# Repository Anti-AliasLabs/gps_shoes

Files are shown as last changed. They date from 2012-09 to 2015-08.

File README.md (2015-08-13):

gps_shoes
=========

Project with Dominc Wilcox and Stamp Shoes to create GPS shoes.

ChooseHome is a Processing sketch to select the location for the shoes to guide to.
Requires Processing 1.5.1 and Processing libraries:

* [Unfolding](http://unfoldingmaps.org/)
* [GLGraphics](http://glgraphics.sourceforge.net/)
* [guicomponents](https://code.google.com/p/gui4processing/downloads/list)
* [processing-http](https://github.com/francisli/processing-http/wiki)

Bill of Materials
-----------------

V1

* Arduino Pro Mini
* [LiPo Charger](https://www.sparkfun.com/products/11231)
* [Kingbright LEDs](https://uk.rs-online.com/web/p/visible-leds/4663970/)
* Reed switch
* [GPS](https://www.sparkfun.com/products/8975)
* [Cable assembly](https://uk.rs-online.com/web/p/industrial-automation-cable-assemblies/6813155/)
* [PCB Header](https://uk.rs-online.com/web/p/pcb-headers/6813111/)
* [Connector housing](https://uk.rs-online.com/web/p/pcb-connector-housings/6813082/)

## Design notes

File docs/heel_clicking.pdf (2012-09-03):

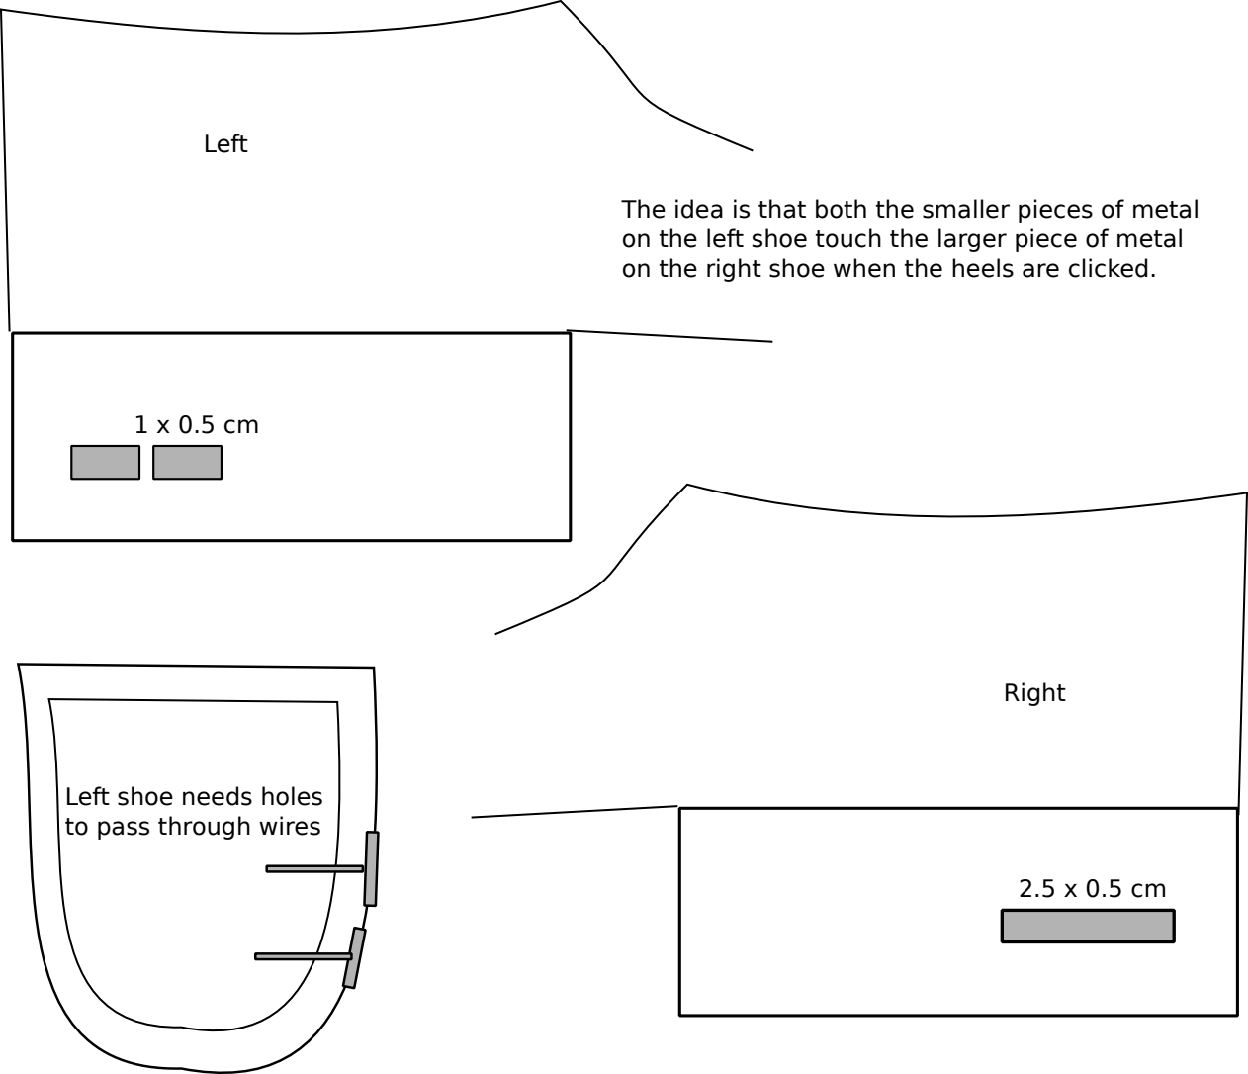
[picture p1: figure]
Left; Right; Left shoe needs holes to pass through wires

The idea is that both the smaller pieces of metal on the left shoe touch the larger piece of metal on the right shoe when the heels are clicked.

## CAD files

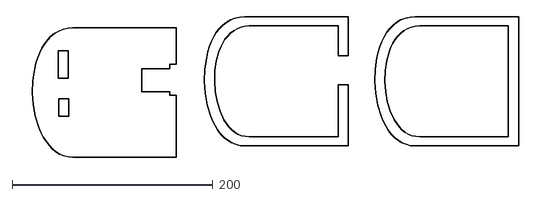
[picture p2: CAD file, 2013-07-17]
docs/heel_boxes.dxf
500.0 x 140.7

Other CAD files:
docs/heel_boxes_.dxf

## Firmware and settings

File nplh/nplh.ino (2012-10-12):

/* 
 No Place Like Home
 Becky Stewart
 Codasign
 becky@codasign.com
 July 2012
 
 Serial port reads in GPS data and writes out
 instructions to remote XBee controlling LEDS.
 
 
 
 */

#include <TinyGPS.h>
#include <VirtualWire.h>
#include <SoftwareSerial.h>

SoftwareSerial softSerial(3, 4); // RX, TX

const int gpsIn = 1;
const int heelPin = 2;

int centreLED = 5;
int ledPins[] = {
  6, 13, 14, 15, 16, 17, 8, 7};

int ledsLen = 8;
/*
 N  6
 NE 13
 E  14
 SE 15
 S  16
 SW 17
 W  8
 NW 7
 */

int fadeValue = 0;
int fadeDirection = 2;

unsigned long lastGPSfeed;

const unsigned long timeLimit = 5000;
const int triggerNum = 3;

unsigned long initDetect;
int currCount = 0;

int goHome = 0;


int headingValue;
float startLat = 0.0;
float startLon = 0.0;

TinyGPS gps;

float homeLat = 37.6922, homeLon = 97.3372;

//---------------------------------------------------------------------------------
// setup - called once at startup
//---------------------------------------------------------------------------------
void setup()
{
  Serial.begin(57600);
  softSerial.begin(9600);

  // set up interrupt for heel clicks
  pinMode(heelPin, INPUT); 
  digitalWrite(heelPin, HIGH);
  attachInterrupt(0, heelClicked, CHANGE);

  // set up LED display
  for (int i=0; i<ledsLen; i++){
    pinMode(ledPins[i], OUTPUT); 
  }

  // Initialise the IO and ISR
  vw_set_ptt_inverted(true); // Required for DR3100
  vw_setup(2000);	 // Bits per sec

  // initialise GPS reading timer
  lastGPSfeed = millis();
}

//---------------------------------------------------------------------------------
// loop - called continuously while powered
//---------------------------------------------------------------------------------
void loop()
{
  bool newdata = false;
  unsigned long loopStart = millis();

  // if it's been longer than the time limit
  // reset the counter
  if ( currCount > 0 && (loopStart-initDetect) > timeLimit )
  {
    currCount = 0; 
    softSerial.println("resetting counter");
  }

  // heels have been clicked
  if ( currCount >= triggerNum && (timeLimit-initDetect) )
  {
    // print the results to the serial monitor:
    softSerial.print("starting directions " );  
    softSerial.println(currCount);
    currCount = 0;
    goHome = 1;
  }

  // we are showing directions
  if ( goHome ){
    // Every second we print an update
    while ( millis() - loopStart < 1000)
    {
      if (feedgps())
        newdata = true;
    }
    // spin lights if we don't have a signal
    // show directions if we do
    updateGPS(gps);
  }
  else {
    standby();
  }
}

//---------------------------------------------------------------------------------
// gpsdump - reads in GPS data
//---------------------------------------------------------------------------------
static void updateGPS(TinyGPS &gps)
{
  float flat, flon;
  unsigned long age, date, time, chars = 0;
  unsigned short sentences = 0, failed = 0;
  unsigned long invalid = 0;


  gps.f_get_position(&flat, &flon, &age);

  // if GPS isn't receiving a signal, just flash lights
  if(TinyGPS::GPS_INVALID_F_ANGLE == flat || TinyGPS::GPS_INVALID_F_ANGLE == flon) {
    Serial.println("invalid position"); 
    spinLights();
  }
  // if receiving a signal, go ahead and compute location and distance
  else{
    // get current course
    softSerial.print("Current Latitude: ");
    softSerial.print(flat);
    softSerial.print(" Current Longitude: ");
    softSerial.print(flon);

    // keep track of where we are once we've started 
    // navigating home (to keep track of distance travelled
    // once we start going home)
    if ( goHome && startLat == 0.0 && startLon == 0.0) {
      startLat = flat;
      startLon = flon;
    }

    // update directions
    int total_dist = TinyGPS::distance_between(startLat, startLon, homeLat, homeLon) / 1000;
    int dist_travelled = TinyGPS::distance_between(startLat, startLon, flat, flon) / 1000;
    float current_course = gps.f_course(); 
    float course_to_home = TinyGPS::course_to(flat, flon, homeLat, homeLon);

    // send distance to right shoe for lights
    int d = dist_travelled/total_dist * 6.0;
    sendDistanceToRight(d);
    Serial.print(" Current Course: ");
    Serial.print(TinyGPS::cardinal(gps.f_course()));
    Serial.print(" ");
    Serial.print(current_course);
    Serial.print(" ");

    
    Serial.print(" To go ");
    Serial.print(dist_travelled);
    Serial.print(" ");
    Serial.print(d);
    Serial.print(" ");
    Serial.println(course_to_home);
    const char *str = TinyGPS::cardinal(course_to_home);
    updateLightsHeading(current_course, course_to_home);

  }
}


//---------------------------------------------------------------------------------
// feedgps - returns true if GPS data available
//---------------------------------------------------------------------------------
static bool feedgps()
{
  while (Serial.available())
  {
    if (gps.encode(Serial.read()))
      return true;
  }
  return false;
}

//---------------------------------------------------------------------------------
// heelClicked - increments counter for heel clicks
//---------------------------------------------------------------------------------
void heelClicked() {
  currCount++;
  Serial.println("click");
  // if this is the first knock
  // note the time
  if ( currCount == 1 )
  {
    initDetect = millis(); 
  }
}

//---------------------------------------------------------------------------------
// standby - standby power light
//---------------------------------------------------------------------------------
void standby(){
  // fade centre from min to max in increments of 5 points:
  analogWrite(centreLED, fadeValue);  

  fadeValue += fadeDirection;
  if(fadeValue > 253 || fadeValue < 2)
    fadeDirection = -1*fadeDirection;  


  delay(30);
}

//---------------------------------------------------------------------------------
// spinLights - spinning light pattern
//---------------------------------------------------------------------------------
void spinLights()
{
  digitalWrite(centreLED, LOW);
  for (int i=0; i<ledsLen; i++){
    digitalWrite(ledPins[i], HIGH); 
    delay(200);
    digitalWrite(ledPins[i], LOW); 
  }
}

//---------------------------------------------------------------------------------
// updateLightsHeading - update light indicating north
//---------------------------------------------------------------------------------
void updateLightsHeading(float c, float h)
{
  // turn off all LEDs
  for (int i=0; i<ledsLen; i++){
    digitalWrite(ledPins[i], LOW); 
  }

  //given a heading and a direction, calculate which of 8
  // LEDs should light up (valued 0-7)
  float relativeAngle;
  int ledOn;

  // calculate relative angle 
  relativeAngle = c-h;

  // ensure relative angle is in the range 0-360
  relativeAngle = modulo360((int)relativeAngle);

  // calculate LED based upon borders of (x*45)+22.5 degrees for x = (0...7) 
  ledOn = floor(modulo360(relativeAngle+22.5)/45);

  digitalWrite(centreLED, LOW);
  delay(100);
  digitalWrite(centreLED, HIGH);
  digitalWrite(ledPins[ledOn], HIGH);
  softSerial.println(ledOn);
}

//---------------------------------------------------------------------------------
// modulo360: simple modulo 360. Negative numbers are set within
// the 0-360 range which is not done by built in Processing modulo
//---------------------------------------------------------------------------------
float modulo360(int val)
{
  // ifval is < 0, set it within 0-360
  while (val < 0)
  {
    val = val+360;
  }

  // if val is > 360, set within 0-360
  val = val % 360;

  return val;
}

//---------------------------------------------------------------------------------
// sendDistanceToRight - sends an int between 1 and 6 to right shoe
//---------------------------------------------------------------------------------
void sendDistanceToRight(int dist)
{
  uint8_t msg[] = {
    dist    };

  vw_send(msg, 1);
  vw_wait_tx(); // Wait until the whole message is gone
}

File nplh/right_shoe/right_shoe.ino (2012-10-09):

// receiver
//
// Receiver for right shoe of GPS shoes
// rf receiver in pin 11

#include <VirtualWire.h>

// first LED with PWM fading needs to be in 3 (or same port)
int leds[] = {
  3, 17, 16, 15, 14};
int numLEDs = 5;
int currBlink = 0;

int j =0;
int fadeValue = 0;
int fadeDirection = 5;

void setup()
{
    Serial.begin(9600);	// Debugging only
    Serial.println("setup");
    
    for( int i=0; i<numLEDs; i++)
    {
      pinMode(leds[i], OUTPUT);
    }

    // Initialise the IO and ISR
    vw_set_ptt_inverted(true); // Required for DR3100
    vw_setup(2000);	 // Bits per sec

    vw_rx_start();       // Start the receiver PLL running
}

void loop()
{
    uint8_t buf[VW_MAX_MESSAGE_LEN];
    uint8_t buflen = VW_MAX_MESSAGE_LEN;

    if (vw_get_message(buf, &buflen)) // Non-blocking
    {
	int i;

        digitalWrite(13, true); // Flash a light to show received good message
	// Message with a good checksum received, dump it.
	Serial.print("Got: ");
	
	for (i = 0; i < buflen; i++)
	{
            currBlink = buf[i];
            Serial.print("received: ");
	    Serial.println(currBlink);
	}

        digitalWrite(13, false);
    }
    
    distance_lights(currBlink);
    
    //Serial.println("test");
    //delay(1000);
}


void distance_lights(int pos)
{ 
  //Serial.print("blinking position: ");
  //Serial.println(pos);
  //Serial.print(" ");
  // simulate distance to destination
  if(pos > 0) {
    if(pos < 6){
    for(int i=0; i<=numLEDs-1; i++)
    {
      digitalWrite(leds[i], LOW);
    }

    for(int i=0; i<pos-1; i++){
      digitalWrite(leds[i], HIGH);
    }
    digitalWrite(leds[pos-1], HIGH);
    delay(300);
    digitalWrite(leds[pos-1], LOW);
    delay(300);
    j++;
    if(j>50) j=0;
    }
    else {
      for(int i=0; i<=numLEDs-1; i++)
    {
      digitalWrite(leds[i], HIGH);
    }
    }
  } 
  // simulate standby
  else {
    // fade centre from min to max in increments of 5 points:
    analogWrite(leds[0], fadeValue);  

    fadeValue += fadeDirection;
    if(fadeValue > 250 || fadeValue < 5)
      fadeDirection = -1*fadeDirection;  


    delay(50);
    //Serial.println(fadeValue);
  }
}

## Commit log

2012-08-28 Added distance tracking to Arduino code.
2012-09-03 Basic working Arduino sketch with all features except updating location, though not thoroughly tested.
2012-09-03 Added files for laser cutting.
    [heel_boxes_.dxf]
2012-09-04 Added GUI library for buttons. Basic interface.
2012-09-05 Removed zoom buttons.
2012-09-18 Added Arduino code for right shoe including wireless functionality
2012-10-03 Updated tests and right shoe with latest pins for LEDs
2012-10-10 Right shoe sketch now switches states correctly and reads in GPS data. Doesn't yet communicate wirelessly or display direction.
    [nplh.ino]
2012-10-10 Changed back control flow around feedgps() and added RF TX for distance.
2012-11-27 Fixed clicking within instructions box bug
    [ChooseHome.pde]
2012-11-27 Replaced buttons with image buttons and added instructions again
    [ChooseHome.pde]
2012-11-27 Added zoom functionality to buttons
2013-07-17 Version 2 of heel boxes
    [heel_boxes.dxf]
2015-08-13 Updated README with BOM from first build of shoes
